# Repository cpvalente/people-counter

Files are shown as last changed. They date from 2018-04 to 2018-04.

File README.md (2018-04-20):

  # people-counter

  People Counter - Sender Node

  Program detects events from PIR sensor and sends and counter over i2c <br />
  Programmed to be paired with people-seven code <br />
  Programmed to run on Adafruit Adalogger 32u4 <br />

  ### TO-DO

 ```
  - Add file header
  - Make BOM
 ```

  ### Implemented

 ```
  - Send I2C information to displays
  - SD operations
  -- Log CSV (a bit silly without RTC, implemented anyway)
  -- Read value from SD if it exists
  - Serial for debug and comm
  - Value from digitalInterrupt
  - Handling timing rollover
 ```

  ### Extend

 ```
  - Better handle interval between measurements
  - DEBUG mode
  - Add RTC
  - Communications, see AdaLight https://github.com/adafruit/Adalight/blob/master/Arduino/LEDstream/LEDstream.pde
 ```

  ### NOTES

 ```
  Serial Events not working with adalogger
  Events have noInterrupt()
  Arduino SD library returned false readings after certain number of entries (~400)
 ```

  ### License

  This project is licensed under the MIT License - see the [LICENSE.md](LICENSE.md) file for details

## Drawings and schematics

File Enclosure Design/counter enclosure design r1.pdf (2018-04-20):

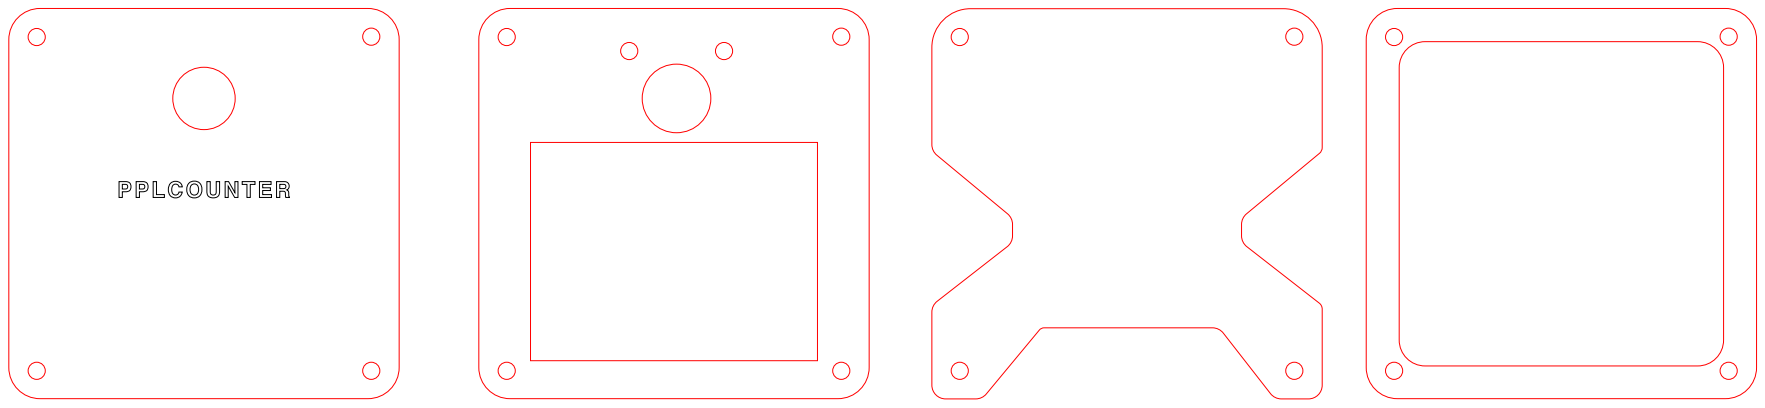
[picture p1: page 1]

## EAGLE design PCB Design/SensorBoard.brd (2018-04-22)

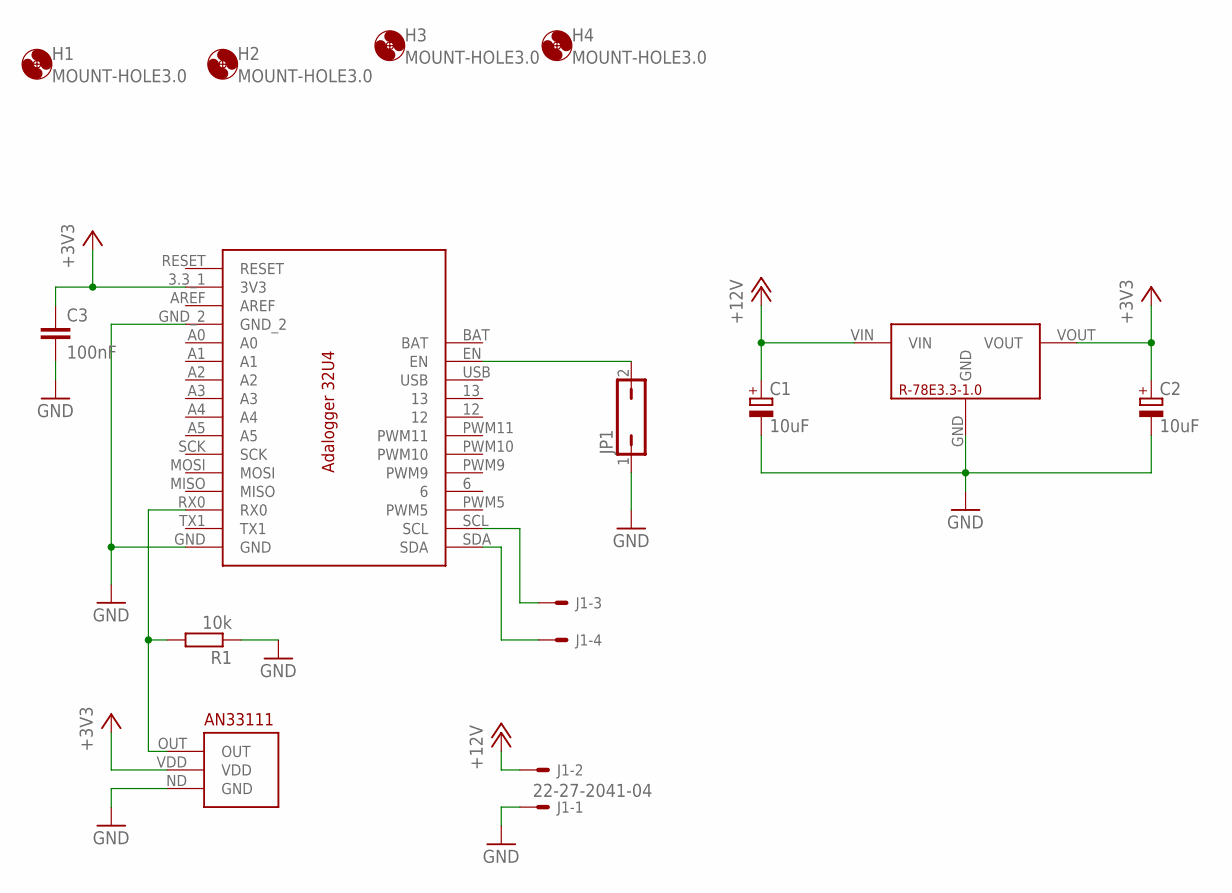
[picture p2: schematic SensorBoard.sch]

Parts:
C1, C2: 10uF; E2,5-7
C3: 100nF; C050-025X075
H1, H2, H3, H4: MOUNT-HOLE3.0; 3,0
J1: 22-27-2041-04; 6410-04
JP1: JP1Q; JP1
R1: 10k; 0207/7
U$1: ADALOGGER_32U4_BOARD
U$2: AMN33111; AN33111
U$3: R-78E3.3-1.0

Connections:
+3V3: C2.+, C3.1, U$1.3.3_1 (3V3), U$2.VDD, U$3.VOUT
+12V: C1.+, J1.2, U$3.VIN
GND: C1.-, C2.-, C3.2, J1.1, JP1.1, R1.1, U$1.GND, U$1.GND_2, U$2.ND (GND), U$3.GND
unnamed: R1.2, U$1.RX0, U$2.OUT
unnamed: JP1.2, U$1.EN
SCL: J1.3, U$1.SCL
SDA: J1.4, U$1.SDA

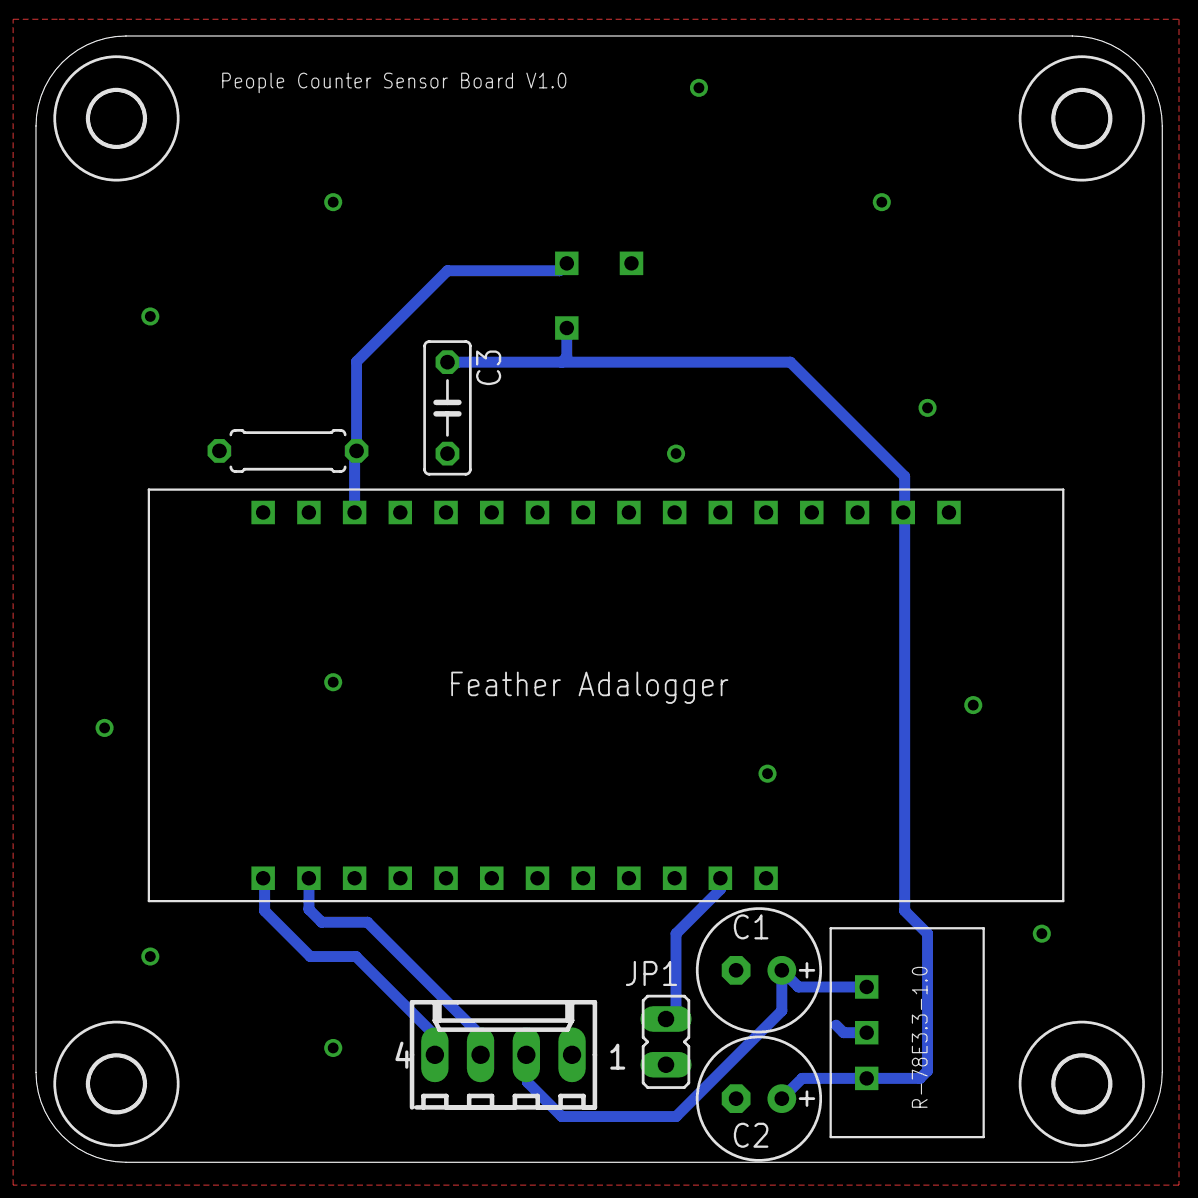
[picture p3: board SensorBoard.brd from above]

Board: 2 copper layers, 62.6 x 62.6 mm, 13 parts (1 on the bottom side), 7 nets.

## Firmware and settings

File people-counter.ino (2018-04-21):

/*
  People counter
  Working but not finished
*/

#include "DEFINITIONS.h"

// ================ | DATA LOGGING
File logFile;
unsigned long counter = 0;

// ================ | I2C
extern uint16_t twi_readFrom_timeout;
extern uint16_t twi_writeTo_timeout;
extern bool twi_readFrom_wait;
extern bool twi_writeTo_wait;

// ================ | TIMERS
long timerPIR;
long lastBroadcast;

// ================ | AUX
bool bSafeTrigger = false;


void setup() {
  // ================ | INIT Comms - I2C
  Wire.begin();                    // join i2c bus
  twi_readFrom_wait = false;       // Suppress twi_readFrom() waiting loop
  twi_writeTo_wait = false;        // Suppress twi_writeTo() waiting loop

  Wire.onReceive(receiveEvent);    // register event handlers
  Wire.onRequest(requestEvent);

  // ================ | INIT Comms - Serial Debug
  Serial.begin(9600);
  delay(1000);
  Serial.println("PEOPLE COUNTER STARTED");

  // ================ | INIT DATA
  initFromSD();
  Serial.print("Starting with counter: ");
  Serial.println(counter);

  // ================ | INIT SENSOR
  pinMode(SENSOR_PIN, INPUT_PULLUP);
  attachInterrupt(INTERRUPT_PIN, motionDetected, HIGH);

  // ================ | INIT Aux Variables
  timerPIR = millis() + WARM_UP_TIME;
}

void loop() {
  /* Transmit values every BROADCAST_TIME */
  if (millis() - lastBroadcast >= BROADCAST_TIME){
    sendSimpleData();
    lastBroadcast = millis();
  }
}

void motionDetected() {
  /* Handler for digital interrupt from PIR sensor */
  if ((long)millis() - timerPIR < 0) // avoid double readings
    return;

  if (!bSafeTrigger) {              // Good readings on second high
    bSafeTrigger = true;
    timerPIR = millis() + SAFE_TIME;
    return;
  }

  noInterrupts();
  bSafeTrigger = false;
  counter++;                        // increment counter

  Serial.println("Movement Detected");
  Serial.print("Count: ");
  Serial.println(counter);

  sendSimpleData();                 // data to i2c
  logToFile(counter);               // log event to SD
  timerPIR = millis() + DEBOUNCE_TIME;
  interrupts();
}

inline long iPow(int base, int exp){
  /* long based pow(), always returns int */
  long result = 1;
  while (exp){
    if (exp & 1)
      result *= base;
    exp /= 2;
    base *= base;
  }
  return result;
}

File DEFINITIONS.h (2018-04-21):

#ifndef DEFINITIONS_H
#define DEFINITIONS_H

// ================ | LIBRARIES
#include <Arduino.h>
#include <jm_Wire.h>      // i2c communications, arduino Wire problematic
#include <SPI.h>
#include <SD.h>

// ================ | SENSOR STUFF
#define SENSOR_PIN    0  // sensor pin
#define INTERRUPT_PIN 2  // interrupt associated to pin
#define DIGITS_SIZE   6  // how many digits in number

#define WARM_UP_TIME   45000
#define DEBOUNCE_TIME  7000
#define BROADCAST_TIME 3000
#define SAFE_TIME      500
// ================ | COMMS
#define SLAVE_ADDRESS 1  // address of slave (single slave scenario)

#define SS_CHECK    0x21	// !
#define SS_WRBIN    0x00	// Write new value from bin
#define SS_WRVAL    0x01	// Write neww value from char
#define SS_WBRI     0x02	// Set Brightness
#define SS_RBOT     0x03  // Reboot
#define SS_MODE     0x04  // Change mode
#define SS_ACK      0x00  // Do acknowledge
#define SS_NO_ACK   0x01  // Do NOT acknowledge

// ================ | LOGGING
#define CHIPSELECT    4
#define FILENAME "datalog.csv"  // where data is saved
#define CSV_DELIM ","

// ================ | UTIL
#define intToByteArray(i) static_cast<char*>(static_cast<void*>(&i))
#define charDtoInt(c) (int)(c - 48) // will only be correct for decimals

#endif

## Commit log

2018-03-15 first commit
    Prototyping stage code
    Functional but untested
2018-03-18 fixed timing rollover issues
    [DEFINITIONS.h, people-counter.ino]
2018-03-21 interrupts, untested
2018-04-20 bug fixes
    separed into multiple files
    [DEFINITIONS.h, comms_stuff.ino, people-counter.ino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]
2018-04-20 enclosure design
2018-04-22 Initial Commit
    PCB Design for sensor + feather
    [SensorBoard.brd, SensorBoard.sch]
